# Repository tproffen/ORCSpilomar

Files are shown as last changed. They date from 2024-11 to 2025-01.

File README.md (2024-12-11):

# pi-lomar

## ORCSGirls version

We build this project with one of our students. This is the home for some of the code modifications. 

* Change driver to TMC2209 and control via UART
* New draft PCB to enable UART control of the stepper controllers.

## Based on this project

RaspberryPi based miniature observatory.
A Python3 project to control a small camera and telephoto lens housed in a miniature 3D printed observatory enclosure.
This combines multiple open modules to handle object location, tracking and image capture.

This uses Python3 on the Raspberry Pi and CircuitPython on a connected Pimoroni Tiny2040/Tiny2350 microcontroller.

The physical telescope, mechanism and dome is buildable from the Instructables page.
[https://www.instructables.com/Pi-lomar-3D-Printed-Working-Miniature-Observatory-/]

The wiki for pi-lomar is here.
[https://github.com/Short-bus/pilomar/wiki]

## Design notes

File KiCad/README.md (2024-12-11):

# Circuit Boards

Initial draft *untested* version ot a new PDB allowing UART control of the TMC2209.

The version also includes a connection for a [GPS module](https://learn.adafruit.com/adafruit-ultimate-gps) and a [Temperature and Pressure Sensor](https://learn.adafruit.com/adafruit-am2320-temperature-humidity-i2c-sensor)connected to the I2C bus of the Pi. The board also has two buttons (HOME and STOP) connected to the Pi GPIOs for future use. 

Use at your own risk :)

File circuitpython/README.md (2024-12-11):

# Code for the microcontroller

## Tiny2040
This contains the unchanged code for the Tiny2040 controller taking in to account the limited computer power and memory.

## Tiny2350
This contains the unchanged code for the new Tiny2350 controller. You can run this code with the TMC2209 divers rather than the DRV8825. However, this requires these changes if you are using the original pilomar PCB:

* Remove the header pins for M2, AZ-F and ALT-F from Tiny. Run wire from Tiny 5V to AZ-F and ALT-F which will supply the needed 5V to the new stepper controllers.  

* On the bottom of the PCB run a wire from the 5V pin of the Tiny controller to the pins labelled AZ-F and ALT-F. THese connect to the logic 5V in on the TMC2209 (same location as the fault pin on the DRV8825). Note that in this configuration the fault detection will (obvioulsy) not work.

* Remove (bottom) header pins PDN,PDN,CLK from the new controller. These pins are also accessible from the top on some boards. 

No software changes needed, except for an update to the microstepping parameters in `data/pilomar_params.json` to match the microstepping selected with M0 and M1. 

## Tiny2350-tmc2209
This code is a very early draft version to use the UART interface of the TMC2209 stepper controllers. Because the Tiny only supports two UART connections (and one is used for talking to the Raspberry Pi), we use one UART to address both steppers. The driver board can have their ID set using the M0 and M1 pins. For details check the draft schematics and board in the `KiCad` folder.

The TMC driver code is based on https://github.com/Chr157i4n/TMC2209_Raspberry_Pi

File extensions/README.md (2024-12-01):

Here is the place for extensions - currently some code to red the GPS

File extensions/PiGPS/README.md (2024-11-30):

# PiGPS

Adaped the <a href="https://github.com/adafruit/Adafruit_CircuitPython_GPS">Adafruit CircuitPython GPS library</a> to run on the Raspberry Pi and added some examples. Tested with the <a href="https://www.adafruit.com/product/5440">Adafruit Ultimate GPS Breakout</a> board.

This will be running on the <a href="https://www.instructables.com/Pi-lomar-3D-Printed-Working-Miniature-Observatory-/">Pilomar telescope</a> which uses the default uart. The Raspberry Pi 4 allows to run multiple UARTs at the same time. To enable, add these lines to `/boot/config.txt`

```
# Enable UART5 for GPS
dtoverlay=uart5
```

We are using UART5 which uses GPIO pints 12 and 13 which are broken out on the Pilomar PCB :)

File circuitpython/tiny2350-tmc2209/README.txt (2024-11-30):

Code for the Tiny2350 with TMC2209 drivers

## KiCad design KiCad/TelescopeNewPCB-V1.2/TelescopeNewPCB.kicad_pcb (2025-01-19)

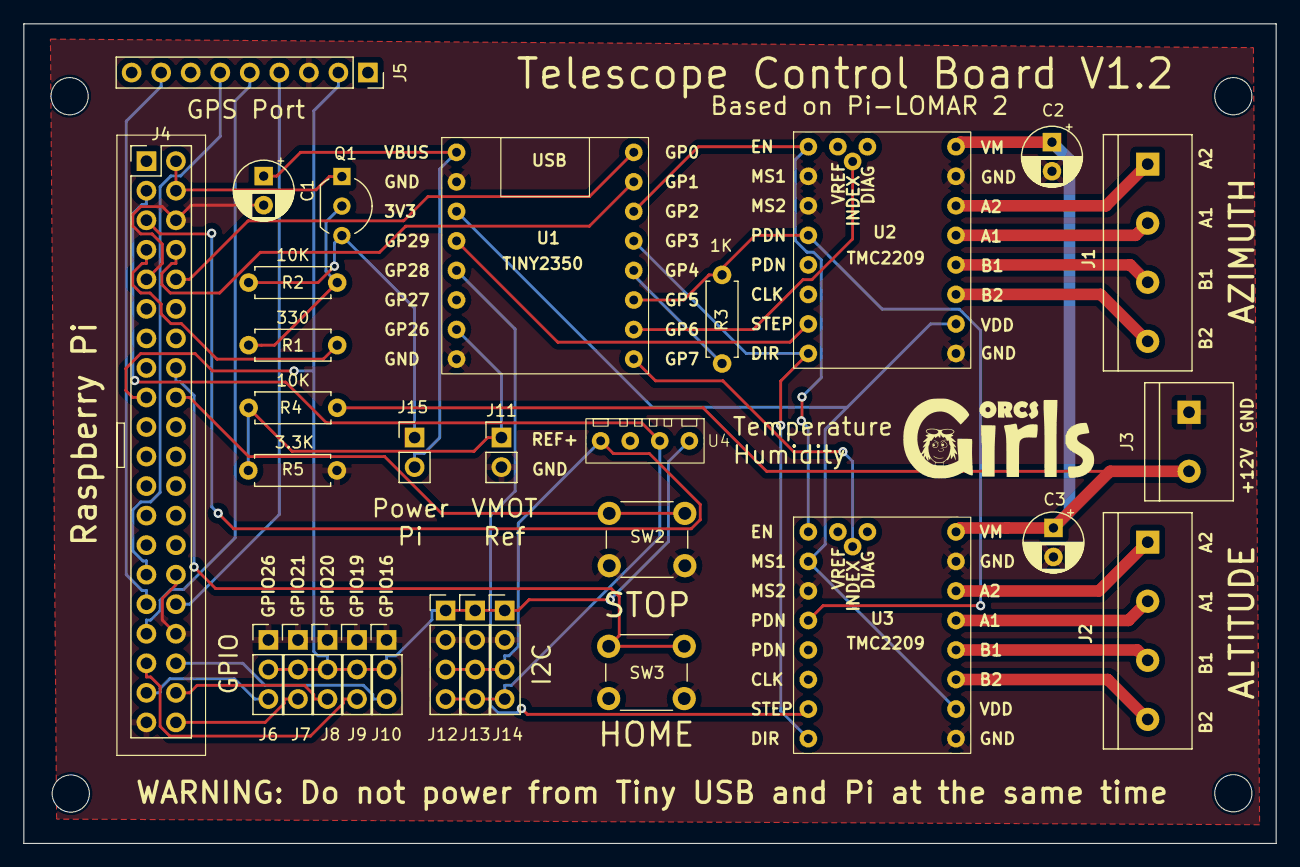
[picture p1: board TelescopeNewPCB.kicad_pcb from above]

Board: 2 copper layers, 107.7 x 70.5 mm, 35 parts (0 on the bottom side), 41 nets.

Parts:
C1, C2, C3: 47uF; CP_Radial_D5.0mm_P2.50mm
G99: LOGO
H1, H2, H3, H4: MountingHole_3.2mm_M3
J1: Azimuth; TerminalBlock_bornier-4_P5.08mm
J2: Altitude; TerminalBlock_bornier-4_P5.08mm
J3: Power 12V; TerminalBlock_bornier-2_P5.08mm
J4: Pi Connector; PinHeader_2x20_P2.54mm_Vertical
J5: GPS Module; PinSocket_1x09_P2.54mm_Vertical
J6: GPIO26; PinHeader_1x03_P2.54mm_Vertical
J7: GPIO21; PinHeader_1x03_P2.54mm_Vertical
J8: GPI20; PinHeader_1x03_P2.54mm_Vertical
J9: GPI19; PinHeader_1x03_P2.54mm_Vertical
J10: GPI16; PinHeader_1x03_P2.54mm_Vertical
J11: VMOTRef; PinHeader_1x02_P2.54mm_Vertical
J12, J13, J14: I2C; PinHeader_1x04_P2.54mm_Vertical
J15: TinyPower; PinHeader_1x02_P2.54mm_Vertical
Q1: BC548; TO-92_Inline_Wide
R1: 330; R_Axial_DIN0207_L6.3mm_D2.5mm_P7.62mm_Horizontal
R2, R4: 10K; R_Axial_DIN0207_L6.3mm_D2.5mm_P7.62mm_Horizontal
R3: 1K; R_Axial_DIN0207_L6.3mm_D2.5mm_P7.62mm_Horizontal
R5: 3.3K; R_Axial_DIN0207_L6.3mm_D2.5mm_P7.62mm_Horizontal
SW2: HOME; SW_PUSH_6mm_H5mm
SW3: STOP; SW_PUSH_6mm_H5mm
U1: Tiny2350
U2, U3: TMC2209
U4: AM2320

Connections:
3V3: U1.3 (3V3), U2.10 (VCC), U3.2 (MS1), U3.10 (VCC)
5V: J4.2, J4.4, Q1.1 (C)
ALTDIAG: U1.16 (GP7), U3.19 (DIAG)
ALTSTEP: U1.5 (GP28), U3.7 (STEP)
AZMDIAG: U1.15 (GP6), U2.19 (DIAG)
AZMSTEP: U1.4 (GP29), U2.7 (STEP)
DIR: U1.12 (GP3), U2.8 (DIR), U3.8 (DIR)
EN: U1.11 (GP2), U2.1 (EN), U3.1 (EN)
GND: C1.2, C2.2, C3.2, J3.1, J4.6, J4.9, J4.30, J4.34, J4.39, J5.3, J6.1, J7.1, J8.1, J9.1, J10.1, J11.2, J12.2, J13.2, J14.2, R5.2, SW2.2, SW3.2, U1.2 (GND), U1.8 (GND), U2.2 (MS1), U2.3 (MS2), U2.9 (GND), U2.15 (GND), U3.3 (MS2), U3.9 (GND), U3.15 (GND), U4.3 (GND)
GPIO16: J4.36, J10.3
GPIO19: J4.35, J9.3
GPIO20: J4.38, J8.3
GPIO21: J4.40, J7.3
GPIO26: J4.37, J6.3
GPSEN: J4.31, J5.8
GPSFIX: J4.29, J5.6
GPSRX: J4.32, J5.4
GPSTX: J4.33, J5.5
unnamed: J1.1, U2.14 (A2)
unnamed: J1.2, U2.13 (A1)
unnamed: J1.3, U2.12 (B1)
unnamed: J1.4, U2.11 (B2)
unnamed: J2.1, U3.14 (A2)
unnamed: J2.2, U3.13 (A1)
unnamed: J2.3, U3.12 (B1)
unnamed: J2.4, U3.11 (B2)
unnamed: J4.16, SW3.1
unnamed: J4.18, SW2.1
unnamed: J11.1, R4.1, R5.1, U1.7 (GP26)
unnamed: J15.1, Q1.3 (E), R2.2
unnamed: Q1.2 (B), R1.2, R2.1
unnamed: R3.1, U1.13 (GP4)
RX2TX: J4.10, U1.9 (GP0)
SCL: J4.5, J12.3, J13.3, J14.3, U4.4 (SCL)
SDA: J4.3, J12.4, J13.4, J14.4, U4.2 (SDA)
TSWITCH: J4.7, R1.1
TX2RX: J4.8, U1.10 (GP1)
UART: R3.2, U1.14 (GP5), U2.4 (PDN), U3.4 (PDN)
VIN: J4.17, J5.2, J6.2, J7.2, J8.2, J9.2, J10.2, J12.1, J13.1, J14.1, U4.1 (VDD)
VMOT: C2.1, C3.1, J3.2, R4.2, U2.16 (VM), U3.16 (VM)
VTINY: C1.1, J15.2, U1.1 (VBUS)

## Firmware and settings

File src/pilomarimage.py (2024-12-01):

#!/usr/bin/python

# image class for use in Pilomar project.
# Builds upon opencv features to provide pilomar specific routines.
# Some methods are just simplifications of existing opencv routines, such as line drawing, circles, etc.
# Some methods are enhancements adding some more features to existing opencv functions.
# There are also some methods which are very specific to the pilomar miniature observatory project.

# This software is published under the GNU General Public License v3.0.
# Also respect any pre-existing terms of any components that this incorporates.

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
import cv2 # OpenCV.
import numpy as np # Numpy array handling.
from datetime import datetime, timezone, timedelta
import math
import random # random number generator.
import os
from PIL import Image as PIL_Image
from PIL import ExifTags as PIL_ExifTags

class data_set():
    """ Data set list of data points. """
    def __init__(self,name,color=None,style=['line']):
        self.Name = name
        self.DataPoints = []
        self.Color = color
        self.Style = style
        
    def Add(self,point):
        self.DataPoints.append(point)
        
    def Clear(self):
        self.DataPoints = []
        
class data_point():
    """ Datapoint. """
    def __init__(self,x,y,color=None,label=None,style=['dot'],xname=None,yname=None):
        self.X = x
        self.Y = y
        self.Color = color
        self.Label = label
        self.Style = style
        self.XName = xname
        self.YName = yname

class fd_object():
    """ Object to be placed in an image (for force directed graphs). """
    def __init__(self):
        self.Name = None
        self.Type = None
        self.Width = None # Dimensions of object.
        self.Height = None
        self.InitialX = None # Centre of object.
        self.InitialY = None
        self.Fixed = False
        self.CurrentX = self.InitialX # Centre of object.
        self.CurrentY = self.InitialY
        self.TargetX = self.InitialX # Centre of object.
        self.TargetY = self.InitialY
        
class fd_edge():
    """ Link between to objects (for force directed graphs). """
    def __init__(self):
        self.Name = None
        self.ObjectA = None # Handle to object at one end of the edge.
        self.ObjectB = None # Handle to object at the other end of the edge.

class pilomarimage():

    # Constants.
    __version__ = '0.1.0'
    IMAGETYPES = ['bgr','bgra','grayscale']
    # COLORPOINTS is used to estimate a RGB color from a Hipparcos star catalog star B-V value.
    COLORPOINTS = [(-0.33,[0x70,0x6f,0xfe]),
                   (-0.3,[0x51,0x9f,0xfe]),
                   (-0.02,[0xbf,0xd0,0xff]),
                   (0.3,[0xcd,0xfd,0xff]),
                   (0.58,[0xee,0xff,0xdf]),
                   (0.81,[0xff,0xff,0x7f]),
                   (1.4,[0xfe,0x7f,0x7d])]
    # Color names for OpenCV drawing. (Beware colors are BGR not RGB!)
    # Official HTML colors 3 Channel BGR colors only. 
    # Make all BGR colors available as a dictionary. Easier to search and manipulate.
    BGRColor = {
        "Black":(0,0,0),
        "Night":(10,9,12),
        "Charcoal":(44,40,52),
        "Oil":(49,49,59),
        "DarkGray":(60,59,58),
        "LightBlack":(69,69,69),
        "BlackCat":(57,56,65),
        "Iridium":(58,60,61),
        "BlackEel":(63,62,70),
        "BlackCow":(70,70,76),
        "GrayWolf":(75,74,80),
        "VampireGray":(81,80,86),
        "IronGray":(93,89,82),
        "GrayDolphin":(88,88,92),
        "CarbonGray":(93,93,98),
        "AshGray":(98,99,102),
        "DimGray":(105,105,105),
        "NardoGray":(108,106,104),
        "CloudyGray":(104,105,109),
        "SmokeyGray":(109,110,114),
        "AlienGray":(110,111,115),
        "SonicSilver":(117,117,117),
        "PlatinumGray":(121,121,121),
        "Granite":(124,126,131),
        "Gray":(128,128,128),
        "BattleshipGray":(130,132,132),
        "GunmetalGray":(141,145,141),
        "DarkGray":(169,169,169),
        "GrayCloud":(180,182,182),
        "Silver":(192,192,192),
        "PaleSilver":(187,192,201),
        "GrayGoose":(206,208,209),
        "PlatinumSilver":(206,206,206),
        "LightGray":(211,211,211),
        "SilverWhite":(221,219,218),
        "Gainsboro":(220,220,220),
        "Platinum":(226,228,229),
        "MetallicSilver":(204,198,188),
        "BlueGray":(199,175,152),
        "RomanSilver":(150,137,131),
        "LightSlateGray":(153,136,119),
        "SlateGray":(144,128,112),
        "RatGray":(141,123,109),
        "SlateGraniteGray":(131,115,101),
        "JetGray":(126,109,97),
        "MistBlue":(126,109,100),
        "MarbleBlue":(126,109,86),
        "SlateBlueGrey":(161,124,115),
        "LightPurpleBlue":(206,143,114),
        "AzureBlue":(160,99,72),
        "BlueJay":(126,84,43),
        "CharcoalBlue":(79,69,54),
        "DarkBlueGrey":(91,70,41),
        "DarkSlate":(86,56,43),
        "DeepSeaBlue":(86,52,18),
        "NightBlue":(84,27,21),
        "MidnightBlue":(112,25,25),
        "Navy":(128,0,0),
        "DenimDarkBlue":(141,27,21),
        "DarkBlue":(139,0,0),
        "LapisBlue":(126,49,21),
        "NewMidnightBlue":(160,0,0),
        "EarthBlue":(165,0,0),
        "CobaltBlue":(194,32,0),
        "MediumBlue":(205,0,0),
        "BlueberryBlue":(194,65,0),
        "CanaryBlue":(245,22,41),
        "Blue":(255,0,0),
        "SamcoBlue":(255,2,0),
        "BrightBlue":(255,9,9),
        "BlueOrchid":(252,69,31),
        "SapphireBlue":(199,84,37),
        "BlueEyes":(199,105,21),
        "BrightNavyBlue":(210,116,25),
        "BalloonBlue":(222,96,43),
        "RoyalBlue":(225,105,65),
        "OceanBlue":(236,101,43),
        "BlueRibbon":(255,110,48),
        "BlueDress":(236,125,21),
        "NeonBlue":(255,137,21),
        "DodgerBlue":(255,144,30),
        "GlacialBlueIce":(193,139,54),
        "SteelBlue":(180,130,70),
        "SilkBlue":(199,138,72),
        "WindowsBlue":(199,126,53),
        "BlueIvy":(199,144,48),
        "BlueKoi":(199,158,101),
        "ColumbiaBlue":(199,175,135),
        "BabyBlue":(199,185,149),
        "CornflowerBlue":(237,149,100),
        "SkyBlueDress":(255,152,102),
        "Iceberg":(236,165,86),
        "ButterflyBlue":(236,172,56),
        "DeepSkyBlue":(255,191,0),
        "MiddayBlue":(255,185,59),
        "CrystalBlue":(255,179,92),
        "DenimBlue":(236,186,121),
        "DaySkyBlue":(255,202,130),
        "LightSkyBlue":(250,206,135),
        "SkyBlue":(235,206,135),
        "JeansBlue":(236,207,160),
        "BlueAngel":(236,206,183),
        "PastelBlue":(236,207,180),
        "LightDayBlue":(255,223,173),
        "SeaBlue":(255,223,194),
        "HeavenlyBlue":(255,222,198),
        "RobinEggBlue":(255,237,189),
        "PowderBlue":(230,224,176),
        "CoralBlue":(236,220,175),
        "LightBlue":(230,216,173),
        "LightSteelBlue":(222,207,176),
        "GulfBlue":(236,223,201),
        "PastelLightBlue":(234,214,213),
        "LavenderBlue":(250,228,227),
        "WhiteBlue":(250,233,219),
        "Lavender":(250,230,230),
        "Water":(250,244,235),
        "AliceBlue":(255,248,240),
        "GhostWhite":(255,248,248),
        "Azure":(255,255,240),
        "LightCyan":(255,255,224),
        "LightSlate":(255,255,204),
        "ElectricBlue":(255,254,154),
        "TronBlue":(254,253,125),
        "BlueZircon":(255,254,87),
        "Aqua":(255,255,0),
        "Cyan":(255,255,0),
        "BrightCyan":(255,255,10),
        "Celeste":(236,235,80),
        "BlueDiamond":(236,226,78),
        "BrightTurquoise":(245,226,22),
        "BlueLagoon":(236,235,142),
        "PaleTurquoise":(238,238,175),
        "PaleBlueLily":(236,236,207),
        "LightTeal":(217,217,179),
        "TiffanyBlue":(208,216,129),
        "BlueHosta":(199,191,119),
        "CyanOpaque":(199,199,146),
        "NorthernLightsBlue":(199,199,120),
        "BlueGreen":(181,204,123),
        "MediumAquaMarine":(170,205,102),
        "MagicMint":(209,240,170),
        "LightAquamarine":(232,255,147),
        "Aquamarine":(212,255,127),
        "BrightTeal":(198,249,1),
        "Turquoise":(208,224,64),
        "MediumTurquoise":(204,209,72),
        "DeepTurquoise":(205,204,72),
        "Jellyfish":(199,199,70),
        "BlueTurquoise":(219,198,67),
        "DarkTurquoise":(209,206,0),
        "MacawBlueGreen":(199,191,67),
        "LightSeaGreen":(170,178,32),
        "SeafoamGreen":(159,169,62),
        "CadetBlue":(160,158,95),
        "DeepSea":(156,156,59),
        "DarkCyan":(139,139,0),
        "TealGreen":(127,130,0),
        "Teal":(128,128,0),
        "TealBlue":(128,124,0),
        "MediumTeal":(95,95,4),
        "DarkTeal":(93,93,4),
        "DeepTeal":(62,62,3),
        "DarkSlateGray":(60,56,37),
        "Gunmetal":(57,53,44),
        "BlueMossGreen":(91,86,60),
        "BeetleGreen":(126,120,76),
        "GrayishTurquoise":(126,125,94),
        "GreenishBlue":(126,125,48),
        "AquamarineStone":(129,135,52),
        "SeaTurtleGreen":(128,141,67),
        "DullSeaGreen":(117,137,78),
        "DarkGreenBlue":(87,99,31),
        "DeepSeaGreen":(84,103,48),
        "BottleGreen":(78,106,0),
        "SeaGreen":(87,139,46),
        "ElfGreen":(107,138,27),
        "DarkMint":(110,144,49),
        "Jade":(108,163,0),
        "EarthGreen":(111,165,52),
        "ChromeGreen":(96,162,26),
        "Emerald":(120,200,80),
        "Mint":(137,180,62),
        "MediumSeaGreen":(113,179,60),
        "MetallicGreen":(142,157,124),
        "CamouflageGreen":(107,134,120),
        "SageGreen":(121,139,132),
        "HazelGreen":(88,124,97),
        "VenomGreen":(0,140,114),
        "OliveDrab":(35,142,107),
        "Olive":(0,128,128),
        "DarkOliveGreen":(47,107,85),
        "MilitaryGreen":(49,91,78),
        "GreenLeaves":(11,95,58),
        "ArmyGreen":(32,83,75),
        "FernGreen":(38,124,102),
        "FallForestGreen":(88,146,78),
        "IrishGreen":(75,160,8),
        "PineGreen":(68,124,56),
        "MediumForestGreen":(53,114,52),
        "JungleGreen":(44,124,52),
        "CactusGreen":(66,116,34),
        "ForestGreen":(34,139,34),
        "Green":(0,128,0),
        "DarkGreen":(0,100,0),
        "DeepGreen":(8,102,5),
        "DeepEmeraldGreen":(7,99,4),
        "HunterGreen":(59,94,53),
        "DarkForestGreen":(23,65,37),
        "LotusGreen":(37,66,0),
        "SeaweedGreen":(23,124,67),
        "ShamrockGreen":(23,124,52),
        "GreenOnion":(33,161,106),
        "MossGreen":(91,154,138),
        "GrassGreen":(11,155,63),
        "GreenPepper":(44,160,74),
        "DarkLimeGreen":(23,163,65),
        "ParrotGreen":(43,173,18),
        "CloverGreen":(85,160,62),
        "DinosaurGreen":(108,161,115),
        "GreenSnake":(60,187,108),
        "AlienGreen":(23,196,108),
        "GreenApple":(23,196,76),
        "LimeGreen":(50,205,50),
        "PeaGreen":(23,208,82),
        "KellyGreen":(82,197,76),
        "ZombieGreen":(113,197,84),
        "GreenPeas":(92,195,137),
        "DollarBillGreen":(101,187,133),
        "FrogGreen":(142,198,153),
        "TurquoiseGreen":(180,214,160),
        "DarkSeaGreen":(143,188,143),
        "BasilGreen":(130,159,130),
        "GrayGreen":(156,173,162),
        "IguanaGreen":(113,176,156),
        "CitronGreen":(29,179,143),
        "AcidGreen":(26,191,176),
        "AvocadoGreen":(72,194,178),
        "PistachioGreen":(9,194,157),
        "SaladGreen":(53,201,161),
        "YellowGreen":(50,205,154),
        "PastelGreen":(119,221,119),
        "HummingbirdGreen":(23,232,127),
        "NebulaGreen":(23,232,89),
        "StoplightGoGreen":(100,233,87),
        "NeonGreen":(41,245,22),
        "JadeGreen":(110,251,94),
        "LimeMintGreen":(127,245,54),
        "SpringGreen":(127,255,0),
        "MediumSpringGreen":(154,250,0),
        "EmeraldGreen":(23,251,95),
        "Lime":(0,255,0),
        "LawnGreen":(0,252,124),
        "BrightGreen":(0,255,102),
        "Chartreuse":(0,255,127),
        "YellowLawnGreen":(23,247,135),
        "AloeVeraGreen":(22,245,152),
        "DullGreenYellow":(23,251,177),
        "LemonGreen":(2,248,173),
        "GreenYellow":(47,255,173),
        "ChameleonGreen":(22,245,189),
        "NeonYellowGreen":(1,238,218),
        "YellowGreenGrosbeak":(22,245,226),
        "TeaGreen":(93,251,204),
        "SlimeGreen":(84,233,188),
        "AlgaeGreen":(134,233,100),
        "LightGreen":(144,238,144),
        "DragonGreen":(146,251,106),
        "PaleGreen":(152,251,152),
        "MintGreen":(152,255,152),
        "GreenThumb":(170,234,181),
        "OrganicBrown":(166,249,227),
        "LightJade":(184,253,195),
        "LightMintGreen":(211,229,194),
        "LightRoseGreen":(219,249,219),
        "ChromeWhite":(212,241,232),
        "HoneyDew":(240,255,240),
        "MintCream":(250,255,245),
        "LemonChiffon":(205,250,255),
        "Parchment":(194,255,255),
        "Cream":(204,255,255),
        "CreamWhite":(208,253,255),
        "LightGoldenRodYellow":(210,250,250),
        "LightYellow":(224,255,255),
        "Beige":(220,245,245),
        "Cornsilk":(220,248,255),
        "Blonde":(217,246,251),
        "Champagne":(206,231,247),
        "AntiqueWhite":(215,235,250),
        "PapayaWhip":(213,239,255),
        "BlanchedAlmond":(205,235,255),
        "Bisque":(196,228,255),
        "Wheat":(179,222,245),
        "Moccasin":(181,228,255),
        "Peach":(180,229,255),
        "LightOrange":(177,216,254),
        "PeachPuff":(185,218,255),
        "CoralPeach":(171,213,251),
        "NavajoWhite":(173,222,255),
        "GoldenBlonde":(161,231,251),
        "GoldenSilk":(195,227,243),
        "DarkBlonde":(182,226,240),
        "LightGold":(172,229,241),
        "Vanilla":(171,229,243),
        "TanBrown":(182,229,236),
        "DirtyWhite":(201,228,232),
        "PaleGoldenRod":(170,232,238),
        "Khaki":(140,230,240),
        "CardboardBrown":(116,218,237),
        "HarvestGold":(117,226,237),
        "SunYellow":(124,232,255),
        "CornYellow":(128,243,255),
        "PastelYellow":(132,248,250),
        "NeonYellow":(51,255,255),
        "Yellow":(0,255,255),
        "CanaryYellow":(0,239,255),
        "BananaYellow":(22,226,245),
        "MustardYellow":(88,219,255),
        "GoldenYellow":(0,223,255),
        "BoldYellow":(36,219,249),
        "RubberDuckyYellow":(1,216,255),
        "Gold":(0,215,255),
        "BrightGold":(23,208,253),
        "ChromeGold":(68,206,255),
        "GoldenBrown":(23,193,234),
        "DeepYellow":(0,190,246),
        "MacaroniandCheese":(102,187,242),
        "Saffron":(23,185,251),
        "NeonGold":(1,189,253),
        "Beer":(23,177,251),
        "OrangeYellow":(66,174,255),
        "YellowOrange":(66,174,255),
        "Cantaloupe":(47,166,255),
        "CheeseOrange":(0,166,255),
        "Orange":(0,165,255),
        "BrownSand":(77,154,238),
        "SandyBrown":(96,164,244),
        "BrownSugar":(111,167,226),
        "CamelBrown":(107,154,193),
        "DeerBrown":(131,191,230),
        "BurlyWood":(135,184,222),
        "Tan":(140,180,210),
        "LightFrenchBeige":(127,173,200),
        "Sand":(128,178,194),
        "Sage":(138,184,188),
        "FallLeafBrown":(96,181,200),
        "GingerBrown":(98,190,201),
        "BronzeGold":(93,174,201),
        "DarkKhaki":(107,183,189),
        "OliveGreen":(108,184,186),
        "Brass":(66,166,181),
        "CookieBrown":(23,163,199),
        "MetallicGold":(55,175,212),
        "BeeYellow":(23,171,233),
        "SchoolBusYellow":(23,163,232),
        "GoldenRod":(32,165,218),
        "OrangeGold":(23,160,212),
        "Caramel":(23,142,198),
        "DarkGoldenRod":(11,134,184),
        "Cinnamon":(23,137,197),
        "Peru":(63,133,205),
        "Bronze":(50,127,205),
        "TigerOrange":(65,129,200),
        "Copper":(51,115,184),
        "DarkGold":(57,108,170),
        "MetallicBronze":(66,113,169),
        "DarkAlmond":(78,120,171),
        "Wood":(51,111,150),
        "OakBrown":(23,101,128),
        "AntiqueBronze":(30,93,102),
        "Hazel":(24,118,142),
        "DarkYellow":(0,128,139),
        "DarkMoccasin":(57,120,130),
        "KhakiGreen":(93,134,138),
        "MillenniumJade":(124,145,147),
        "DarkBeige":(118,140,159),
        "BulletShell":(96,155,175),
        "ArmyBrown":(96,123,130),
        "Sandstone":(95,109,120),
        "Taupe":(50,60,72),
        "Mocha":(38,61,73),
        "MilkChocolate":(28,59,81),
        "GrayBrown":(53,54,61),
        "DarkCoffee":(47,47,59),
        "OldBurgundy":(46,48,67),
        "WesternCharcoal":(63,65,73),
        "BakersBrown":(23,51,92),
        "DarkBrown":(33,67,101),
        "SepiaBrown":(20,66,112),
        "DarkBronze":(0,74,128),
        "Coffee":(55,78,111),
        "BrownBear":(59,92,131),
        "RedDirt":(23,82,127),
        "Sepia":(44,70,127),
        "Sienna":(45,82,160),
        "SaddleBrown":(19,69,139),
        "DarkSienna":(23,65,138),
        "Sangria":(23,56,126),
        "BloodRed":(23,53,126),
        "Chestnut":(53,69,149),
        "CoralBrown":(56,70,158),
        "ChestnutRed":(44,74,195),
        "Mahogany":(0,64,192),
        "RedGold":(6,84,235),
        "RedFox":(23,88,195),
        "DarkBisque":(0,101,184),
        "LightBrown":(29,101,181),
        "PetraGold":(52,103,183),
        "Rust":(65,98,195),
        "CopperRed":(81,109,203),
        "OrangeSalmon":(81,116,196),
        "Chocolate":(30,105,210),
        "Sedona":(0,102,204),
        "PapayaOrange":(23,103,229),
        "HalloweenOrange":(44,108,230),
        "NeonOrange":(0,103,255),
        "BrightOrange":(31,95,255),
        "PumpkinOrange":(23,114,248),
        "CarrotOrange":(23,128,248),
        "DarkOrange":(0,140,255),
        "ConstructionConeOrange":(49,116,248),
        "IndianSaffron":(34,119,255),
        "SunriseOrange":(81,116,230),
        "MangoOrange":(64,128,255),
        "Coral":(80,127,255),
        "BasketBallOrange":(88,129,248),
        "LightSalmonRose":(107,150,249),
        "LightSalmon":(122,160,255),
        "DarkSalmon":(122,150,233),
        "Tangerine":(97,138,231),
        "LightCopper":(103,138,218),
        "SalmonPink":(116,134,255),
        "Salmon":(114,128,250),
        "PeachPink":(136,139,249),
        "LightCoral":(128,128,240),
        "PastelRed":(128,114,246),
        "PinkCoral":(113,116,231),
        "BeanRed":(89,93,247),
        "ValentineRed":(81,84,229),
        "IndianRed":(92,92,205),
        "Tomato":(71,99,255),
        "ShockingOrange":(60,91,229),
        "OrangeRed":(0,69,255),
        "Red":(0,0,255),
        "NeonRed":(3,28,253),
        "ScarletRed":(0,36,255),
        "RubyRed":(23,34,246),
        "FerrariRed":(26,13,247),
        "FireEngineRed":(23,40,246),
        "LavaRed":(23,34,228),
        "LoveRed":(23,27,228),
        "Grapefruit":(31,56,220),
        "CherryRed":(65,70,194),
        "ChilliPepper":(23,27,193),
        "FireBrick":(34,34,178),
        "TomatoSauceRed":(7,24,178),
        "Brown":(42,42,165),
        "CarbonRed":(42,13,167),
        "Cranberry":(15,0,159),
        "SaffronRed":(20,19,147),
        "CrimsonRed":(0,0,153),
        "RedWine":(18,0,153),
        "WineRed":(18,0,153),
        "DarkRed":(0,0,139),
        "VeryDarkRed":(0,0,10),
        "Maroon":(0,0,128),
        "Burgundy":(26,0,140),
        "Vermilion":(27,25,126),
        "DeepRed":(23,5,128),
        "RedBlood":(0,0,102),
        "BloodNight":(6,22,85),
        "DarkScarlet":(25,3,86),
        "BlackBean":(2,12,61),
        "ChocolateBrown":(15,0,63),
        "Midnight":(23,27,43),
        "PurpleLily":(53,10,85),
        "PurpleMaroon":(65,5,129),
        "PlumPie":(65,5,125),
        "PlumVelvet":(82,5,125),
        "DarkRaspberry":(87,38,135),
        "VelvetMaroon":(77,53,126),
        "RosyFinch":(82,78,127),
        "DullPurple":(93,82,127),
        "Puce":(88,90,127),
        "RoseDust":(112,112,153),
        "PastelBrown":(127,144,177),
        "RosyPink":(129,132,179),
        "RosyBrown":(143,143,188),
        "KhakiRose":(142,144,197),
        "LipstickPink":(147,135,196),
        "PinkBrown":(137,129,196),
        "OldRose":(129,128,192),
        "DustyPink":(148,138,213),
        "PinkDaisy":(163,153,231),
        "Rose":(170,173,232),
        "DustyRose":(166,169,201),
        "SilverPink":(173,174,196),
        "GoldPink":(194,199,230),
        "RoseGold":(192,197,236),
        "DeepPeach":(164,203,255),
        "PastelOrange":(139,184,248),
        "DesertSand":(175,201,237),
        "UnbleachedSilk":(202,221,255),
        "PigPink":(228,215,253),
        "PalePink":(215,212,242),
        "Blush":(232,230,255),
        "MistyRose":(225,228,255),
        "PinkBubbleGum":(221,223,255),
        "LightRose":(205,207,251),
        "LightRed":(203,204,255),
        "WarmPink":(189,198,246),
        "DeepRose":(185,187,251),
        "Pink":(203,192,255),
        "LightPink":(193,182,255),
        "SoftPink":(191,184,255),
        "DonutPink":(190,175,250),
        "BabyPink":(186,175,250),
        "FlamingoPink":(176,167,249),
        "PastelPink":(170,163,254),
        "RosePink":(176,161,231),
        "PinkRose":(176,161,231),
        "CadillacPink":(174,138,227),
        "CarnationPink":(161,120,247),
        "PastelRose":(143,120,229),
        "BlushRed":(148,110,229),
        "PaleVioletRed":(147,112,219),
        "PurplePink":(135,101,209),
        "TulipPink":(124,90,194),
        "BashfulPink":(131,82,194),
        "DarkPink":(128,84,231),
        "DarkHotPink":(171,96,246),
        "HotPink":(180,105,255),
        "WatermelonPink":(133,108,252),
        "VioletRed":(138,53,246),
        "HotDeepPink":(135,40,245),
        "BrightPink":(127,0,255),
        "DeepPink":(147,20,255),
        "NeonPink":(170,53,245),
        "ChromePink":(170,51,255),
        "NeonHotPink":(156,52,253),
        "PinkCupcake":(157,94,228),
        "RoyalPink":(172,89,231),
        "DimorphothecaMagenta":(157,49,227),
        "PinkLemonade":(124,40,228),
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

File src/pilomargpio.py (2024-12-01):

#!/usr/bin/python

# Raspberry Pi GPIO library.
# Presents an interface to the GPIO handlers on the Raspberry Pi SBCs.
# - Different classes can be built to handle different GPIO handlers, 
#   but all should present the same interface to the calling programs.

# This software is published under the GNU General Public License v3.0.
# Also respect any pre-existing terms of any components that this incorporates.

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
GPIO_DRIVER = None
try:
    import RPi.GPIO as GPIO # Handling IO signals. If available.
    GPIO.setmode(GPIO.BCM)
    GPIO_DRIVER = "GPIO"
except: # No support for RPi.GPIO detected.
    pass

try:
    import gpiod # Handling IO signals. If available.
    GPIO_DRIVER = "GPIOD"
except: # No support for GPIOD detected.
    pass

if GPIO_DRIVER == 'GPIOD': # Select the GPIO handling chip.
    try:
        GPIOchip = gpiod.Chip('gpiochip4') # In very early RPi5 Bookworm builds the GPIO chip is 'gpiochip4'.
    except:
        GPIOchip = gpiod.Chip('gpiochip0') # In later RPi5 Bookworm builds the GPIO chip is 'gpiochip0'.

def cleanup_gpio():
    """ Perform cleanup at end of session. """
    GPIO.cleanup()

class inputpin_gpio():
    """ Wrapper for GPIO input pin. 
        Allows different GPIO libraries to be implemented by hiding the actual implementation behind these methods. 
        Pin can be declared as None in which case it's a non-functional device. """
    
    InputPins = [] # List of all defined input pins.
    __library__ = 'RPi.GPIO' # Which GPIO library does this support?
    __version__ = '0.0.0' # What version of the library is this?
    
    def __init__(self,pinbcm,name=None,pull="up",enabled=True,invert=False):
        """ Define a GPIO input pin.
        
            The purpose is to present a common interface to an I/O pin regardless of the underlying
            GPIO package being used. You can create alternative classes which interact with different 
            packages and present the same interface to the program.
        
            pinbcm = the BCM pin number. 
            name is an optional name for the pin. 
            pull = GPIO.PUD_UP for pull up (default HIGH/ON), 
                   GPIO.PUD_DOWN for pull down. (default LOW/OFF)
            enabled = initial enabled(True)/disabled(False) state of the pin.
            invert = False: IsOn returns TRUE for HIGH signal. 
                            IsOff returns TRUE for a LOW signal.
                     True:  IsOn returns TRUE for LOW signal.
                            IsOff returns TRUE for a HIGH signal.

            if pinbcm is None then this is a fake input.
            it behaves as a GPIO input, but doesn't actually link to a GPIO port and always returns the PULL UP/DOWN value. """
        self.Pin = pinbcm # The BCM number of the pin.
        self.Name = name # A reference name of the pin.
        self.Pull = pull.lower() # Is this a PULL_UP or PULL_DOWN input.
        self.Invert = invert # IsOn/IsOff methods invert their value. IsHigh/IsLow remain unchanged.
        if self.Pin != None: self.Enabled = enabled
        else: self.Enabled = False # Dummy pins are always disabled.
        # Set the PULL UP / DOWN config for the input.
        if pull == 'up': self.State = True # Initial state HIGH.
        else: self.State = False # Initial state LOW.
        # If it's a real pin, set it up through GPIO.
        if self.Pin != None: 
            if self.Pull == 'up': GPIO.setup(self.Pin,GPIO.IN,pull_up_down=GPIO.PUD_UP) # Will EARTH when triggered.
            else: GPIO.setup(self.Pin,GPIO.IN,pull_up_down=GPIO.PUD_DOWN) # Will go HIGH when triggered.
        # Append to the global list of all input pins.
        inputpin_gpio.InputPins.append(self) # Add to list of input pins.
        
    def Refresh(self):
        """ Get and store the current state of the pin.
            GPIO.input() returns 0 = Low, 1 = High.
            Convert to 0 = False, 1 = True 
            DISABLED pins always return False (electrical LOW).
            If you want the logical state of the pin after this use IsOn() and IsOff() methods.
            If you want the physical state of the pin after this use IsHigh() and IsLow() methods. """
        if self.Enabled and GPIO.input(self.Pin) != 0: self.State = True # High
        else: self.State = False # Low
        
    def IsHigh(self):
        """ Return TRUE if input is HIGH.
            This is the true electrical state of the pin.
            It does NOT respect the self.Invert flag, use IsOn() for that. """
        self.Refresh() # Get current electrical state of the pin.
        return self.State # Return True/False.
        
    def IsLow(self):
        """ Return TRUE if input is LOW.
            This is the true electrical state of the pin.
            It does NOT respect the self.Invert flag, use IsOff() for that. """
        self.Refresh() # Get current electrical state of the pin.
        return not self.State # Return True/False.
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

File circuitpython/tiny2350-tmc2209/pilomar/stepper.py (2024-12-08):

# Based on https://github.com/Short-bus/pilomar
# Simplified for use with TINY2350

import analogio

from pilomar.tmc2209 import *
from pilomar.enum import *
from pilomar.helpers import *
from pilomar.trajectory import *

AzimuthStepBCM = GPIOpin(board.GP29,'azstep')
AltitudeStepBCM = GPIOpin(board.GP28,'altstep')
CommonDirectionBCM = GPIOpin(board.GP3,'dir')
CommonEnableBCM = GPIOpin(board.GP2,'enable')
AzimuthFaultBCM = GPIOpin(board.GP6,'azfault')
AltitudeFaultBCM = GPIOpin(board.GP7,'altfault')

VMotADC = analogio.AnalogIn(board.GP26)

TMCuart = busio.UART(board.GP4, board.GP5, baudrate=115200)

#-----------------------------------------------------------------------------------------------
# Configuration
#-----------------------------------------------------------------------------------------------

AzimuthStepBCM.SetDirection(digitalio.Direction.OUTPUT)
AzimuthStepBCM.SetValue(False)
AltitudeStepBCM.SetDirection(digitalio.Direction.OUTPUT)
AltitudeStepBCM.SetValue(False)
CommonDirectionBCM.SetDirection(digitalio.Direction.OUTPUT)
CommonDirectionBCM.SetValue(False)
CommonEnableBCM.SetDirection(digitalio.Direction.OUTPUT)
CommonEnableBCM.SetValue(False)
AzimuthFaultBCM.SetDirection(digitalio.Direction.INPUT)
AzimuthFaultBCM.pull = digitalio.Pull.UP
AltitudeFaultBCM.SetDirection(digitalio.Direction.INPUT)
AltitudeFaultBCM.pull = digitalio.Pull.UP

#-----------------------------------------------------------------------------------------------
class steppermotor():
    """ Handler for a NEMA17 stepper motor with TMC2209 driver chip. """

    def __init__(self, name, LogFile, ExceptionCounter, StatusLed, Clock, RPi, id=0):
        self.mtr_id = id
        self.LogFile = LogFile
        self.ExceptionCounter = ExceptionCounter
        self.StatusLed = StatusLed
        self.Clock = Clock
        self.RPi = RPi
        self.Setup_TMC()

        self.MotorName = name
        self.DriverType = 'tmc2209'
        self.Trajectory = trajectory(name, self.LogFile, self.ExceptionCounter, self.Clock)
        self.MotorEnabled = False
        self.CurrentPosition = None
        self.TargetPosition = None
        self.MotorConfigured = False
        self.FaultSensitive = False # Set to TRUE to monitor the 'fault' pin on the DRV8825 chip.
        self.FaultDetected = False # Latch to indicate we've already reported a fault with the DRV8825. Otherwise we overflow the UART comms buffer with warnings.
        self.SendStatus = True # Set to FALSE to disable status messages while downloading batches of data (eg Trajectories)
        self.StatusTimer = timer(name,10) # Set up an internal timer for sending status messages every 10 seconds. Can we overridden by RPi.
        self.FastTime = 0.0005 # The fastest pulse time for moving the motor.
        self.SlowTime = 0.05 # The slowest pulse time for moving the motor.
        self.DeltaTime = 0.003 # The acceleration amount moving from SlowTime to FastTime as the motor gets going.
        self.WaitTime = self.SlowTime # The time between pulses, starts slow, reduces as a move progresses. Resets every time a new target is set.
        self.Orientation = 1 # 1=Fwd, -1=Bkwd. This sets the overall orientation of motion. Compensate for gearing reversing the direction of motion here! It's applied to the DirectionBCM pin when the move is made.
        self.StepDir = 1 # The direction of a particular move +/-1. It always represents a SINGLE FULL STEP.
        self.LastStepDir = 0 # Record the 'last' direction that the motor moved in. Useful for handling gear backlash and handling rotation limits. Starts at ZERO (No direction)
        self.BacklashAngle = 0.0 # This is the angle the motor must move to overcome backlash in the gearing when changing direction.
        self.DriftSteps = 0 # This is the number of steps 'error' that DriftTracking has identified. It must be incorporated back into motor movements as smoothly as possible. Consider backlash etc.
        self.MotorStepsPerRev = None
        self.SlewStepMultiplier = 1 # The number of steps/microsteps taken when making large SLEW moves.
        self.SlewMotor = False # Allow the motor to make faster full-step (but less precise) moves when slewing the telescope large angles.
        self.GearRatio = None # gearratio is the overall gearing of the entire transmission. 60 means 60 motor revs for 1 transmission rev.
        self.AxisStepsPerRev = None
        self.MinAngle = None # Max anticlockwise movement.
        self.MaxAngle = None # Max clockwise movement.
        self.MinPosition = None # Min clockwise movement. Location of limit switch in steps (This is self calibrating when in use).
        self.MaxPosition = None # Max clockwise movement. Location of limit switch in steps (This is self calibrating when in use).
        self.RestAngle = None # The 'rest' position of the axis. Used for calibrating at startup. Typically DUE SOUTH or HORIZONTAL position of the axis.
        self.RestPosition = None
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

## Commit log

2024-12-01 Line endings fixed and some bugs
    [pilomarcamera.py, pilomarcelestrak.py, pilomardisc.py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]
2024-12-08 Woohoo motors move right with new driver :)
2024-12-11 Added PCB
    [TelescopeNewPCB.kicad_pcb, TelescopeNewPCB.kicad_sch]
2025-01-19 Small changes to labels
    [TelescopeNewPCB.kicad_pcb]
